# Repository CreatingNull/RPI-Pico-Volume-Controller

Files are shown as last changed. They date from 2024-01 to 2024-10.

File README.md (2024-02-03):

# NullTek DocumentationRPi Pico Volume Controller






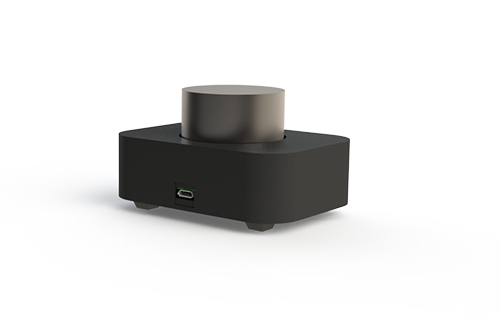
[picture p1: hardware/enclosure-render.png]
Enclosure Render


Turn a Raspberry Pi Pico into a media control device for PC.
Allowing for volume control and play/pause functionality in a stylish self-contained package.

______________________________________________________________________

## Getting Started

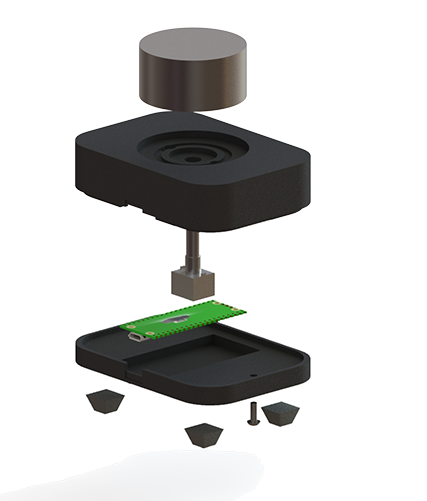
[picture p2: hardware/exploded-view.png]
Exploded-View


**Parts List:**

- 3D Printed `hardware/enclosure-base`
- 3D Printed `hardware/enclosure-lid`
- 4x M2 Threaded Knurled Heatset Inserts
- 2x M3 Threaded Knurled Heatset Inserts
- EC11 Rotor Encoder or Similar
- 4x M2x3 screws
- 2x M3x6 screws
- 4x 12x12mm rubber adhesive feet
- 44mm Aluminium Rotor Encoder / Potentiometer Knob
- Raspberry Pi Pico
- Ribbon Cable
- 2x 5mm LEDs (Optional)

Except the custom 3d printed parts, all the components can be obtained via Aliexpress.

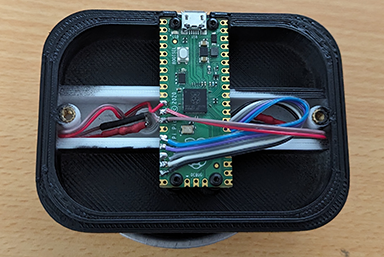
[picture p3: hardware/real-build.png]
full assembly


### Setting up the enclosure

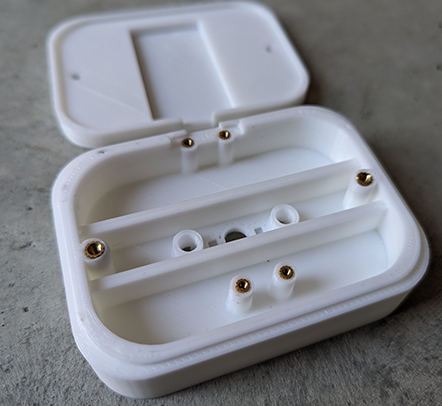
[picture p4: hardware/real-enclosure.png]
enclosure


The enclosure is a 2 piece design designed to be 3d printed.
The `enclosure-lid` is installed with m2 heat-set inserts for securing the raspberry pi, as well as m3 heat-set inserts to securing the base.
There are optional cutouts in the LID to fit standard 5mm LEDs to achieve an illuminated ring under the control knob.

### Wiring the System

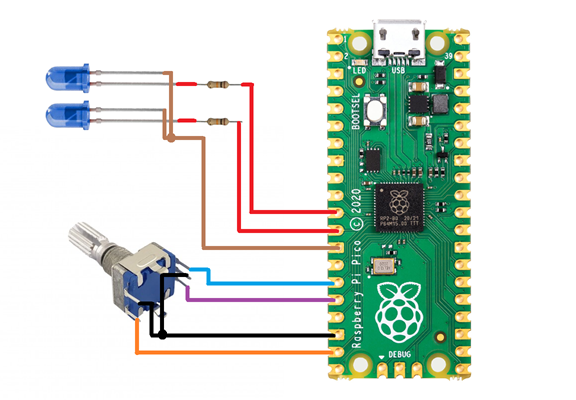
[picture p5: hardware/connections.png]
connections


#### Encoder

The A/B encoder inputs can be directly connected to the GPIO pins 12,11.
Note getting these around backwards (A -> 11, B -> 12) will reverse the volume control direction.
Center ground pin must be connected to the Pico ground.
The switch pins of the encoder should be connected between GPIO Pin 14 and ground.

#### Connecting the optional LEDs

There are cutouts for 2x 5mm LEDs the encoder knob, this can provide an under-glow ring of light effect.
These LEDs can be connected on GPIO pins 8,9 to ground, by default this is driven at 100% duty cycle.
Current limiting resistors should be selected based on LED choice.

### Setting Up The MicroController

This project uses [CircuitPython](https://circuitpython.org/) 8.x for the helpful HID libraries.
Circuit python **8.x** must be installed on the Pico prior to loading the firmware from this repo.
There are also several [adafruit libraries](https://circuitpython.org/libraries) used:

- `adafruit_hid\` - Folder contains the Human Interface Device libs.
- `adafruit_debouncer.mpy` - Used to debounce switch input.
- `adafruit_ticks` - Used for timing within the debouncing lib.

Pre-built versions of the required libraries are vendored in `firmware/lib`.

The firmware should be obtained from the repository [tags](https://github.com/CreatingNull/RPI-Pico-Volume-Controller/tags).
The entire contents of the `firmware/` subdirectory should be copied into the root directory of the Pico device.
Ensure the `firmware/lib` folder contents replaces the `lib/` contents on the pico device.

Note: The storage device is disabled on the next hard boot of the Pi, to disable this behaviour for update or development depress the encoder button on hard reset.

______________________________________________________________________

## Contributing

Any contributions are welcome.
The `requirements-development.txt` file should be installed on a dev python environment to ensure your IDE has typing stubs to introspect your source.

`deploy.py` is provided as a simple helper script to allow automation of loading new code from the repo onto a device for test, this can be configured to run via your IDE.
Pass a directory argument for your Pico when calling the `deploy` script, and any files from `firmware/` not existing on the pi will be copied over.

To expose the storage device for development you need to short the GP14 pin (encoder switch) to ground on boot.

Pre-Commit is used to automate linting and formatting on the repository.

______________________________________________________________________

I just do this stuff for fun in my spare time, but feel free to:

Support via buymeacoffee (https://www.buymeacoffee.com/nulltek)

______________________________________________________________________

## License

The source of this repo uses the MIT open-source license,
for details on the current licensing see:
[LICENSE](https://github.com/CreatingNull/RPI-Pico-Volume-Controller/blob/master/LICENSE.md)
or click the badge above.

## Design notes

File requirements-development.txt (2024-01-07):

# Typing stubs for IDE introspection.
adafruit-circuitpython-debouncer
adafruit-circuitpython-hid
adafruit-circuitpython-ticks
circuitpython-stubs

# Used for linting / formatting automation.
pre-commit

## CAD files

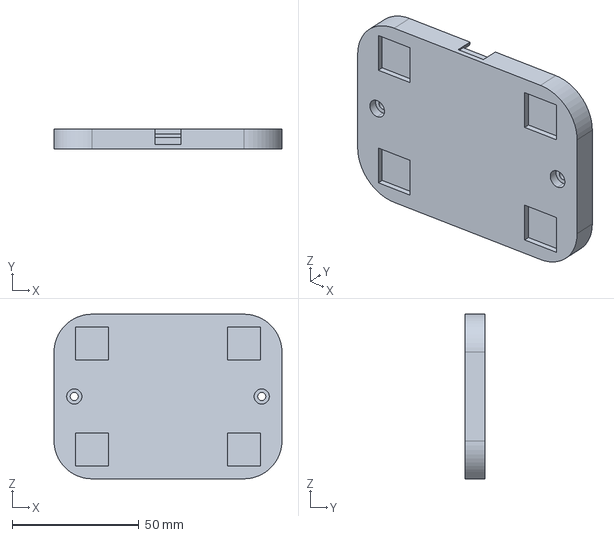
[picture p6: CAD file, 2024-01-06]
hardware/enclosure-base.STEP
90.0 x 8.00 x 65.0 mm

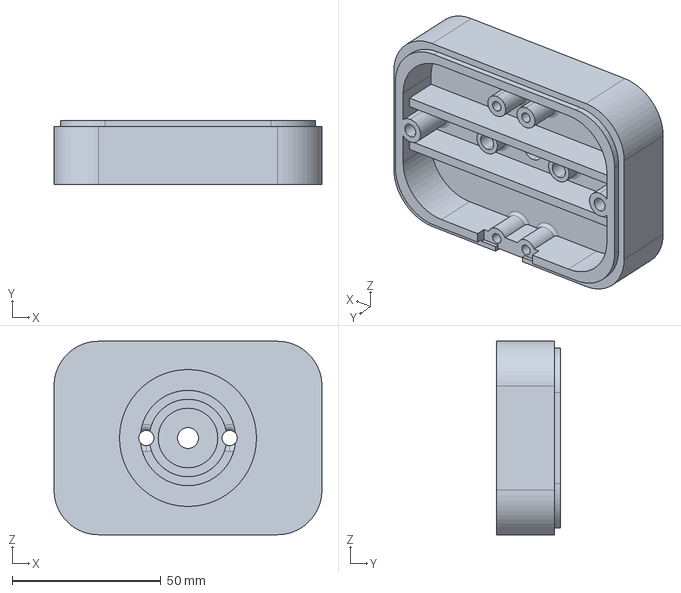
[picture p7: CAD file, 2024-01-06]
hardware/enclosure-lid.STEP
90.0 x 21.5 x 65.0 mm

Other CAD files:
hardware/enclosure-base.STL
hardware/enclosure-lid.STL

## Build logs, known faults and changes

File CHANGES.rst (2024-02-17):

Version 1.0.1
-------------

:Date: 18-February-2024

* Disabled the superfluous pico ``usb_midi`` device.
* Increased the rate-limit from 10Hz to 20Hz.

Version 1.0.0
-------------

:Date: 4-February-2024

* Initial Released Version.

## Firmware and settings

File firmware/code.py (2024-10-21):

"""Use RPI Pico as HID for volume control via a rotor encoder."""

import time

import rotaryio
import usb_hid
from adafruit_debouncer import Debouncer
from adafruit_hid.consumer_control import ConsumerControl
from adafruit_hid.consumer_control_code import ConsumerControlCode
from board import GP8, GP9, GP11, GP12, GP14
from digitalio import DigitalInOut, Direction, Pull
from pwmio import PWMOut

# Set the rate limit for volume changes, 0.05 -> 20Hz, 0.25 -> 5Hz.
# This is to avoid triggering scripting / macro blocking software.
RATE_LIMIT_S = 0.05

# Consumer Control is for Media Keyboard keys
consumer_control = ConsumerControl(usb_hid.devices)

# The push button input on the rotor encoder
button = DigitalInOut(GP14)
button.direction = Direction.INPUT
button.pull = Pull.UP
button_debounced = Debouncer(button)

# First if we have been put into update mode delay start until button is released.
button_debounced.update()
if not button_debounced.value:
    while not button_debounced.value:
        button_debounced.update()
    time.sleep(0.5)  # Delay further to avoid false call on button press

# Switch on the LEDs Pins.
PWMOut(GP8, frequency=1000, duty_cycle=0xFFFF)
PWMOut(GP9, frequency=1000, duty_cycle=0xFFFF)

with rotaryio.IncrementalEncoder(GP12, GP11) as encoder:
    position_prior = encoder.position  # Tracks the n-1 position
    button_latch = True  # False when pending button release.
    last_trigger = time.monotonic()  # for rate-limiting the volume changes.
    while True:
        # Monitor the encoder.
        position = encoder.position
        # If the position has changed.
        if position_prior != position:
            # Check we are within the rate limit.
            current_trigger = time.monotonic()
            if (current_trigger - last_trigger) > RATE_LIMIT_S:
                # Check the polarity of rotation.
                if position > position_prior:  # Increase Volume
                    consumer_control.send(ConsumerControlCode.VOLUME_INCREMENT)
                else:  # Decrease Volume
                    consumer_control.send(ConsumerControlCode.VOLUME_DECREMENT)
                last_trigger = current_trigger
        position_prior = position

        # Monitor the status of the button.
        button_debounced.update()
        if not button_debounced.value and button_latch:
            # Button is pressed so action.
            button_latch = False  # Prevent further actioning until release.
            consumer_control.send(ConsumerControlCode.PLAY_PAUSE)
        elif button_debounced.value and not button_latch:
            button_latch = True

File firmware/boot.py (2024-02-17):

import storage
import usb_cdc
import usb_hid
import usb_midi
from board import GP14
from digitalio import DigitalInOut, Direction, Pull

# If GP14 (encoder switch) is pressed on boot then will enable as a drive to allow updating.
update_jumper = DigitalInOut(GP14)
update_jumper.direction = Direction.INPUT
update_jumper.pull = Pull.UP

if update_jumper.value:
    # Pin is held high by pull-up and drive should be disabled.
    storage.disable_usb_drive()
    # Also disable the serial port.
    usb_cdc.disable()  # No need for the serial devices.
# else we enter update mode and leave the drive / serial enabled.

usb_hid.enable(
    # Disable mouse and keyboard HID as we aren't using these.
    (usb_hid.Device.CONSUMER_CONTROL,)
)

# No need for pico usb_midi device support.
usb_midi.disable()

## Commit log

2024-01-06 Initial functional version of the project.
    [enclosure-base.STEP, enclosure-base.STL, enclosure-lid.STEP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]
2024-01-11 Using the encoder switch to enter update mode on boot rather than requiring GP13 jump. Supporting LED output on GP8, GP9.
2024-02-03 Ratelimiting volume changes to avoid triggering scripting detections. Enabling serial port when in update-mode to allow for easier development. Updating pre-commit hooks. Adding codespell + mdformat.
    [boot.py, code.py]
2024-02-15 [pre-commit.ci] pre-commit autoupdate (#1)
    updates:
    - [github.com/astral-sh/ruff-pre-commit: v0.2.0 → v0.2.1](https://github.com/astral-sh/ruff-pre-commit/compare/v0.2.0...v0.2.1)
2024-02-17 Disabling the usb_midi device. Adjusting rate limit.
2024-02-21 [pre-commit.ci] pre-commit autoupdate (#2)
    - [github.com/astral-sh/ruff-pre-commit: v0.2.1 → v0.2.2](https://github.com/astral-sh/ruff-pre-commit/compare/v0.2.1...v0.2.2)
    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
2024-10-21 [pre-commit.ci] pre-commit autoupdate
    - [github.com/pre-commit/pre-commit-hooks: v4.5.0 → v5.0.0](https://github.com/pre-commit/pre-commit-hooks/compare/v4.5.0...v5.0.0)
    - [github.com/executablebooks/mdformat: 0.7.17 → 0.7.18](https://github.com/executablebooks/mdformat/compare/0.7.17...0.7.18)
    - [github.com/astral-sh/ruff-pre-commit: v0.2.2 → v0.7.0](https://github.com/astral-sh/ruff-pre-commit/compare/v0.2.2...v0.7.0)
    - [github.com/codespell-project/codespell: v2.2.6 → v2.3.0](https://github.com/codespell-project/codespell/compare/v2.2.6...v2.3.0)
    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
2024-10-21 [pre-commit.ci] auto fixes from pre-commit.com hooks
    for more information, see https://pre-commit.ci
    [code.py]
